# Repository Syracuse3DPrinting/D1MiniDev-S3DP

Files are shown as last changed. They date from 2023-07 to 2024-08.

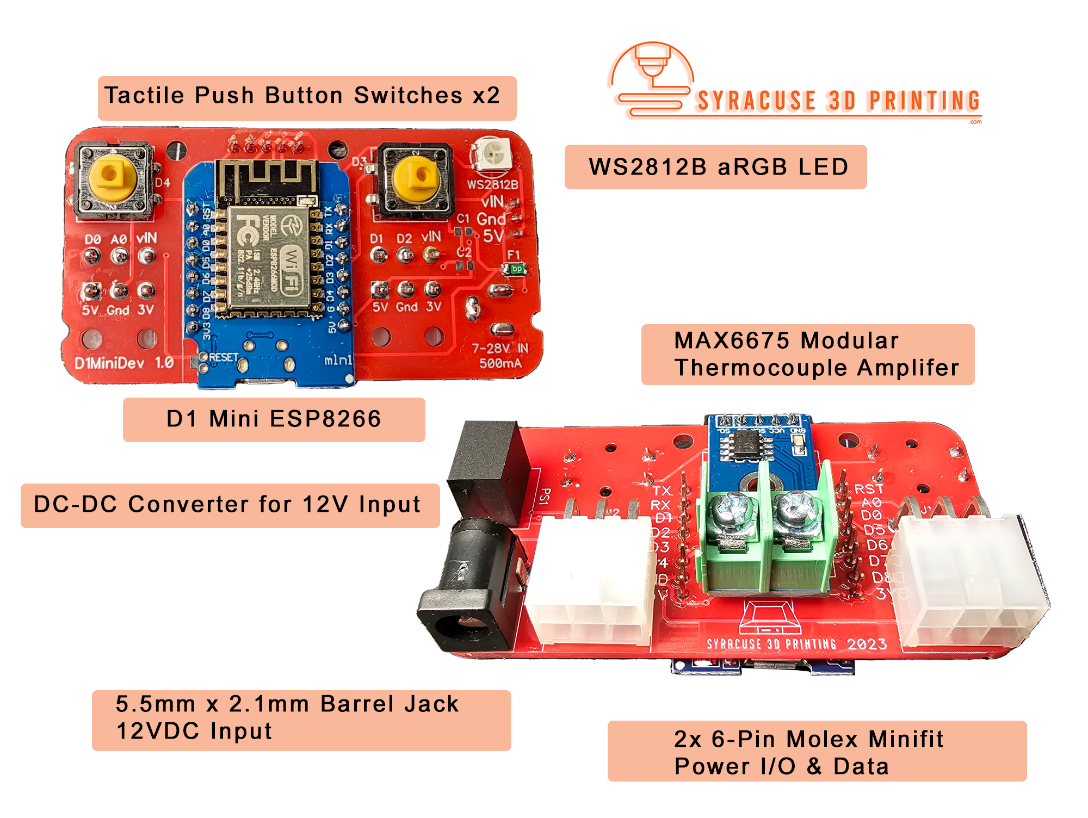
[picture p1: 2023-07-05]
Features.png

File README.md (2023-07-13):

# D1MiniDev-S3DP
## Syracuse 3D Printing D1 Mini Dev Board Resources

### In this repository:
- Technical Specifications & Instructions
- STL Models of Enclosure
- STEP Model of PCB w/Electronics to make your own enclosure
- Sample ESPHome Configuration
- Sample Home Assistant Automation for LED

### Available for purchase here as a bare PCB or fully assembled:
[https://syracuse3dprinting.com/product-category/smart-home/](https://syracuse3dprinting.com/product-category/smart-home/)

The D1MiniDev, designed by Syracuse3DPrinting, is a compact and versatile device ideal for DIY enthusiasts. Utilizing the well-regarded D1Mini ESP8266 microcontroller, this device provides a range of inputs and outputs suitable for a myriad of applications.

### Key Features:

**MAX6675 + K Type Thermocouple**: The device integrates a MAX6675 thermocouple amplifier and a K type thermocouple, which offer precise temperature measurements. This functionality is crucial for projects requiring temperature monitoring, including HVAC diagnostics.

**WS2812B RGB LED**: The D1MiniDev contains a programmable WS2812B RGB LED, which can be customized to change colors based on varying conditions, including temperature fluctuations.

**2x Momentary Push Buttons**: These buttons serve as binary inputs for Home Assistant, enabling users to control various aspects of their smart home system, such as adjusting lighting or activating scenes, directly from the device.

**Power Regulator with 7-28VDC and USB Input**: The D1MiniDev is designed with flexibility in mind, with a power regulator compatible with a wide array of power sources, ranging from 7 to 28VDC and including USB power.

**Dual 6 Pin Molex Minifit Connectors**: The D1MiniDev is equipped with dual 6 pin Molex minifit connectors, facilitating connectivity with other devices or modules and allowing for potential expansion of its functionality.

**ESPHome Configuration**: A sample ESPHome configuration for the D1MiniDev is available for download, ensuring a smooth integration process with the Home Assistant platform.

Users can choose between three different formats for the D1MiniDev: a bare PCB for those interested in a completely hands-on assembly experience; a DIY Kit that includes the PCB and components of your choice; or a fully assembled unit for immediate use. An optional 3D printed enclosure, purchasable or self-printable for those with a 3D printer, is available for added device protection.

### Technical Specifications: D1MiniDev by Syracuse3DPrinting

**Microcontroller**
- D1Mini ESP8266

**Temperature Measurement**
- MAX6675 Thermocouple Amplifier
- K Type Thermocouple

**Visual Indicator**
- WS2812B RGB LED (Programmable)

**User Inputs**
- 2x Momentary Push Buttons (Home Assistant Compatible)
- 3x Digital I/Os via 6-Pin Molex Headers
- 1x Analog I/O via 6-Pin Molex Headers

**Power Options**
- Power Regulator: 7-28VDC Input, 500mA
  - Optional onboard PTC Fuse is limited to 16VDC in
- USB Power Input - 5V via USB on D1 Mini
- Daisy Chain ability - When powered with 12V, Use 6-Pin headers to provide power from one board to another.
  - Recommended to bypass onboard fuse and use external fusing on the power supply for daisy chain applications

**Connectivity**
- Dual 6 Pin Molex Minifit Connectors (For Daisy Chaining and Expandability)
- Smart Home via Wifi (2.4ghz) - Designed for ESPHome via Home Assistant
  - Includes Sample ESPHome Configuration for Home Assistant Integration

**Form Factor Options**
- Bare PCB
- DIY Kit with PCB and Selected Components
- Fully Assembled Device

**Additional Accessories**
- Optional 3D Printed Enclosure (Purchasable or DIY Print)
- Please note that the final assembled size of the device will depend on the chosen components and the use of the optional enclosure.

## Bill of Materials

Most parts are optional based on configuration.

| Component | Specs | Part Number | Link |
| --- | --- | --- | --- |
| DC-DC Converter | 7-28VDCin 5VDC Out 500mA | R-78E5.0-0.5 | [DigiKey](https://www.digikey.com/en/products/detail/recom-power/R-78E5-0-0-5/2834904) |
| Power Supply Filtering Capacitors x2 | 10UF 10V X7R 0805 | CL21B106KPQNNNG | [DigiKey](https://www.digikey.com/en/products/detail/samsung-electro-mechanics/CL21B106KPQNNNG/3894474) |
| Push Button Tactile Switch x2 | - | B3F-4055 | [DigiKey](https://www.digikey.com/en/products/detail/omron-electronics-inc-emc-div/B3F-4055/31799) |
| PTC Resettable Fuse | 750 mA 16V | 0ZCJ0075AF2E | [DigiKey](https://www.digikey.com/en/products/detail/bel-fuse-inc/0ZCJ0075AF2E/4156135) |
| RGB Addressable LED | WS2812B | COM-16347 | [DigiKey](https://www.digikey.com/en/products/detail/sparkfun-electronics/COM-16347/11630204) |
| 6-Pin Molex MiniFit Header | - | 0353180620 | [DigiKey](https://www.digikey.com/en/products/detail/molex/0353180620/3185064) |
| 12V Power Input (5.5x2.1MM Barrel Jack) | - | CON-SOCJ-2155 | [Mouser](https://www.mouser.com/ProductDetail/Gravitech/CON-SOCJ-2155?qs=fkzBJ5HM%252BdCcpvFQyQZHtA%3D%3D) |
| D1 Mini ESP8266 | - | - | [Amazon](https://amzn.to/3rinfvB) |
| MAX6675 Module + K Type Thermocouple | 3-5V M6 | - | [Amazon](https://amzn.to/3rlv4Av) |

## Issues/Limitations

- The silkscreen outline of the ESP8266 is mirrored on v1.0 of the PCB. When assembling follow the assembly pictures instead of using the silkscreen outline for this component.
- The onboard PTC Fuse is limited to 16V. If using a 24VDC power supply it's recommended to bypass this fuse and use an external fuse.
- Some D1Mini clones may have issues with the Windows CH340 Driver. If you are unable to connect to the serial device via USB to PC you may need to roll back your drivers.
  - Here is a known working driver: https://web.archive.org/web/20211129002033/http://www.wch-ic.com/downloads/CH341SER_EXE.html

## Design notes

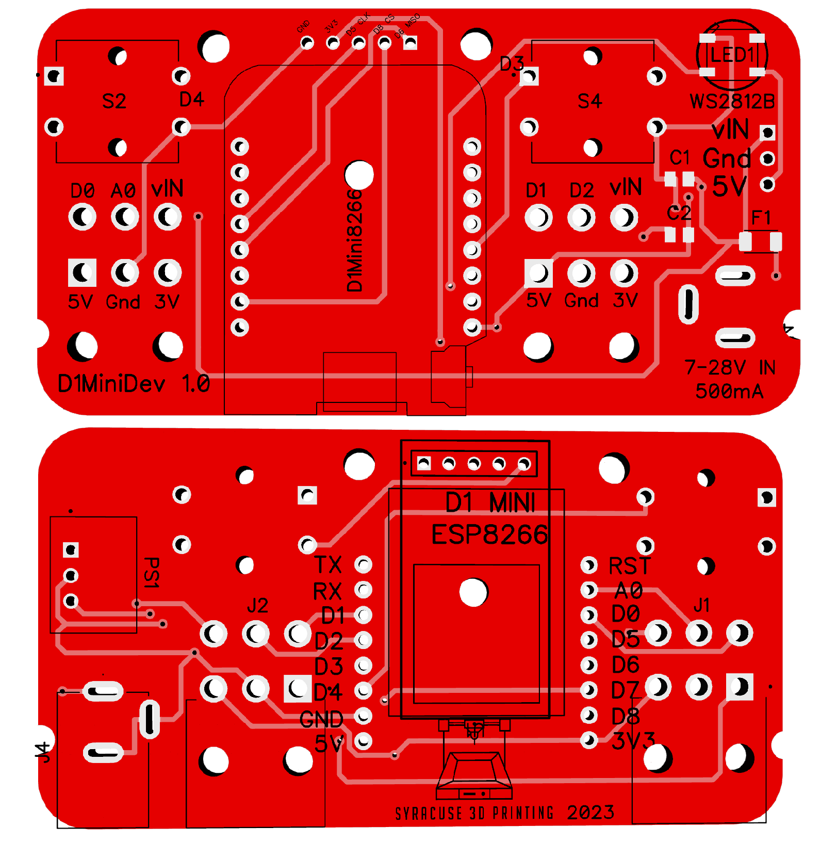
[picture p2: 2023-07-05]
PCB Overview.png

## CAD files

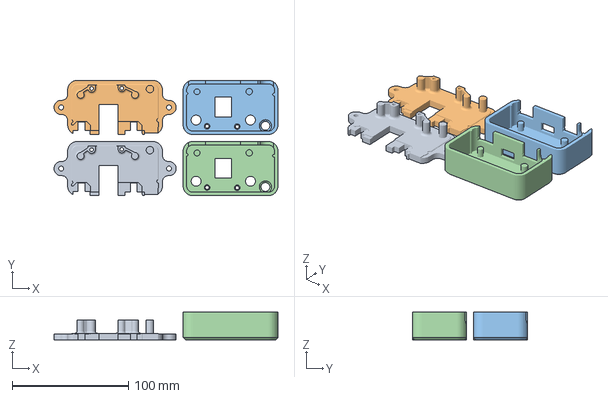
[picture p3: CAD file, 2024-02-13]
Enclosure/Ender3 - D1MiniDevBoardEnclosure1.2.3mf
192.7 x 99.2 x 24.0 mm
D1MiniDevBoardEnclosure1.2.STL_1
D1MiniDevBoardEnclosure1.2.STL_2

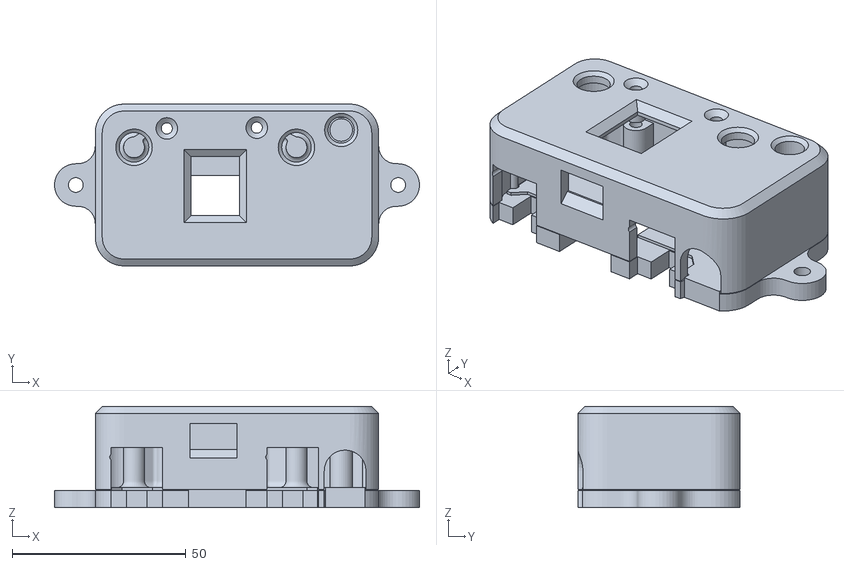
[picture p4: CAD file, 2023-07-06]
Enclosure/D1MiniDevBoardEnclosure1.2.STL
105.1 x 46.6 x 29.2

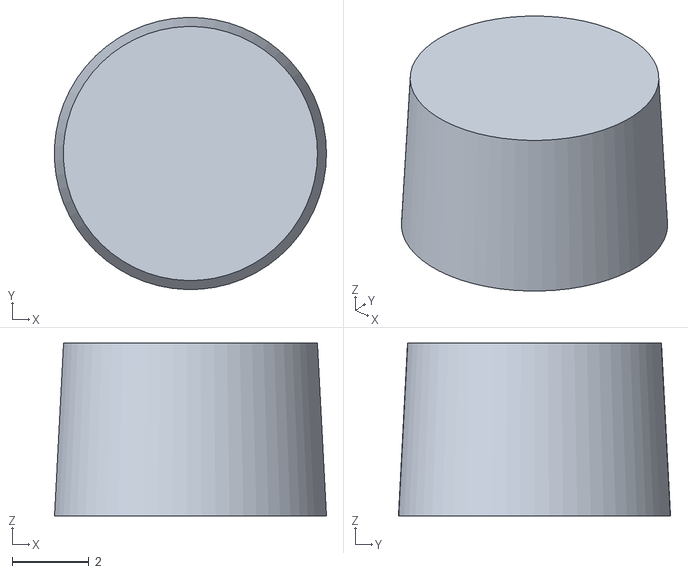
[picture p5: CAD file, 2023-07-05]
Enclosure/Switch Cap.STL
7.09 x 7.10 x 4.50

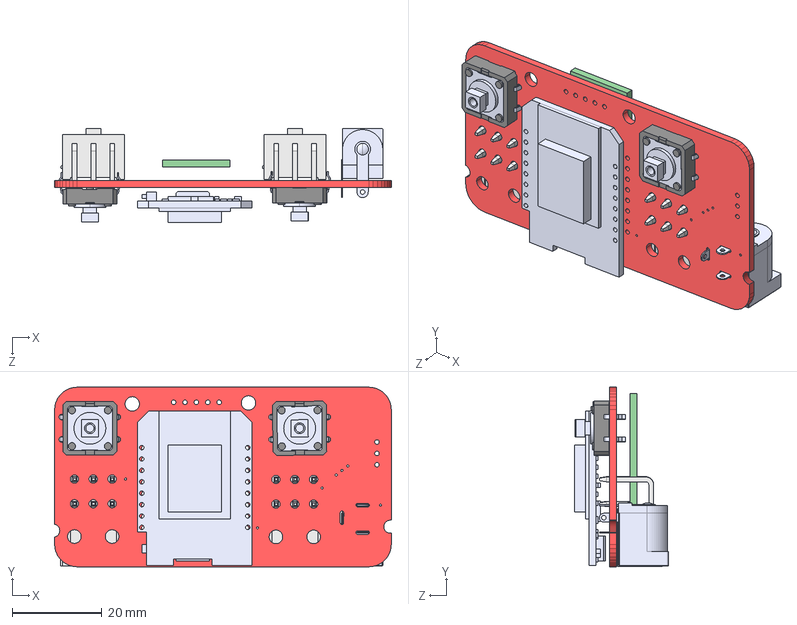
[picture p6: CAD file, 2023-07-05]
Enclosure/D1MiniDevBoardExport.step
75.1 x 40.0 x 21.0 mm
Board_D1MiniDevBoard.step
WEMOS_D1_miniLite.step
353180620.step x 2
CON-SOCJ-2155--3DModel-STEP-56544.step
MAX6675D.step
B3F-40551^B3F-4055.step x 2
B3F-40552^B3F-4055.step x 2
B3F-40553^B3F-4055.step x 2
B3F-40554^B3F-4055.step x 2
B3F-40555^B3F-4055.step x 2
B3F-40556^B3F-4055.step x 2
B3F-40557^B3F-4055.step x 2

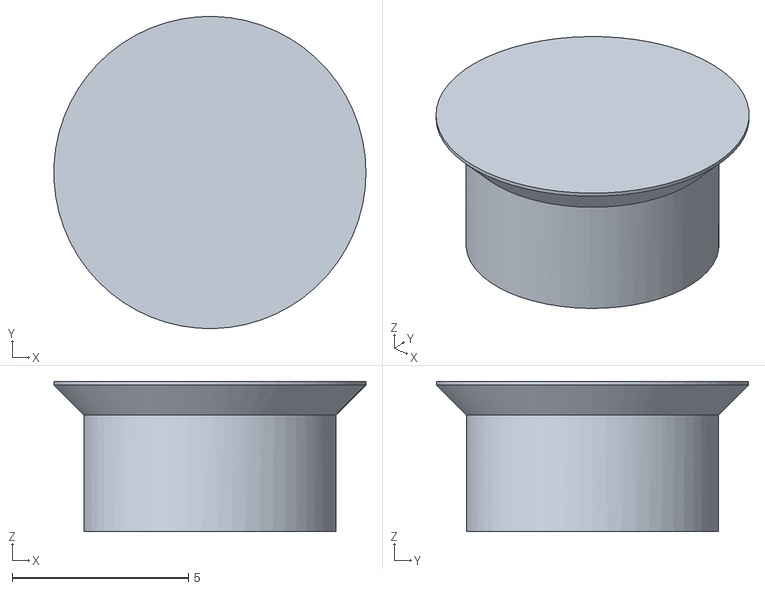
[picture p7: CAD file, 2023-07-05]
Enclosure/LED Lens.STL
8.84 x 8.84 x 4.25

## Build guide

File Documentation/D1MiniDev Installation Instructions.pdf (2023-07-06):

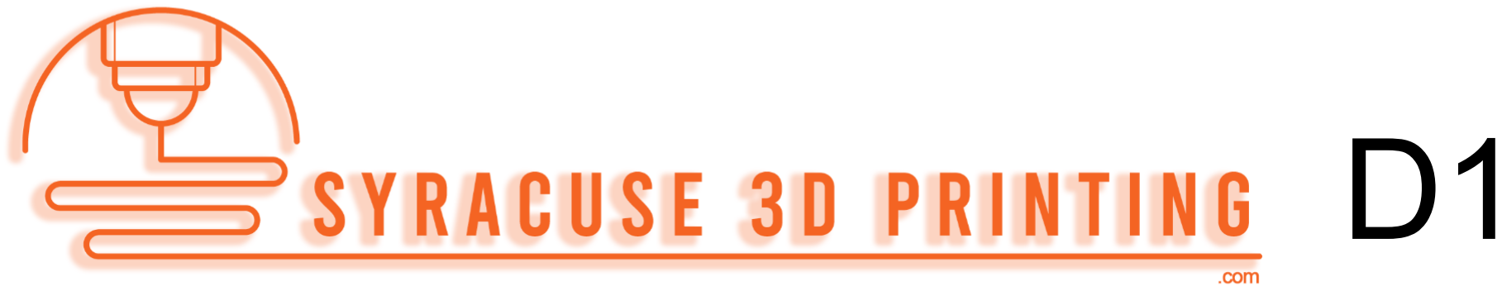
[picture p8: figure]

# D1 Mini Dev Installation Instructions

## Step 1: Physical Setup - Mounting the Thermocouple

1. For the temperature reading, you'll need to mount the K Type thermocouple in your desired location. This often involves drilling a hole and tapping it to match the M6 threading on the thermocouple.
2. Mark the location where you want to install the thermocouple. Make sure that the chosen location is safe for drilling, and will not interfere with other elements or components (like HVAC coils).
3. Drill a hole in the marked location using an appropriate drill bit.
4. Use an M6 tap to thread the hole. Carefully turn the tap to create clean threads.
5. Screw the thermocouple into the newly created hole, ensuring good contact for accurate temperature readings.
6. Connect the red lead to the + connection and the blue lead to the - termina

## Step 2: Wiring & Powering the Device

Depending on your application, the D1MiniDev can be powered via USB or by a 12V power supply.

### Powering via USB

Connect the D1MiniDev to your power source using a standard USB cable. Ensure the USB power source is capable of supplying at least 500mA.

### Powering via 12V - Models with DC-DC Converter installed only

1. Use a 12V DC Power supply with a 5MM barrel plug on it. The power supply should be rated for 750mA or greater. The center pin should be positive.
2. Connect the power supply to the D1MiniDev via the 5.5mm x 2.1mm barrel jack.

### Daisy Chain Power Configuration

For Daisy-Chain applications the 6-pin Molex Minifit connectors can be used to power 1 device from another device. Both devices must have a DC-DC Converter installed. It is recommended to use at least a 1A power. Use only the 12V and ground pins to supply power to a second device.

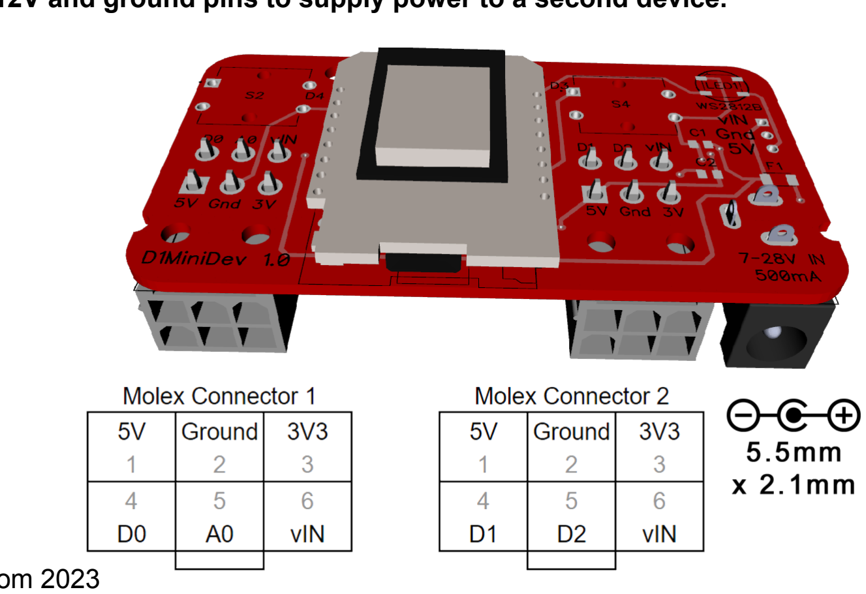
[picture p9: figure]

Syracuse3DPrinting.com 2023

## Step 3: ESPHome Setup

ESPHome is a system to control your ESP8266/ESP32 modules with simple yet powerful configuration files. It's fully integrated with Home Assistant.

1. Open the Home Assistant Dashboard, navigate to the "Supervisor" tab, and then "Add-on Store".
2. Install the ESPHome add-on.
3. In the ESPHome dashboard, click on the "+" button to add a new device.
4. Choose "Generic ESP8266" when asked for the device type.
5. Fill in the Wi-Fi SSID and password, and choose a suitable name for the device.
6. Once the device is online, open its configuration by clicking on "EDIT".
7. Replace the configuration with the provided D1MiniDev.yaml from the root directory of the GitHub repository. Don't forget to keep the Wi-Fi settings, OTA password, and API key generated by ESPHome for your particular installation.
8. Delete any sections that are not relevant to sensors you’re using. For instance if you do not have push buttons installed you can delete the binary sensor section.
9. You should now have a notification that a new device has been found. Follow the steps to set up this new device.
10. After completing these steps, your device should be ready for use, with the ability to monitor temperatures using the thermocouple and control the WS2812B RGB LED via Home Assistant.

## Step 4: 3D Printed Enclosure

The 3D Printed enclosure can be found on the main github repository. For assembly you’ll need the following:
- M3 x 30mm Flat Head Socket Bolts x2
- M3 Hex Nuts x2

Feel free to explore further possibilities of the device, such as setting up automations, customizing the LED behavior, or adding more devices to your smart home system.

## Disclaimer

Please note, this guide is provided for informational purposes only. All users are encouraged to independently validate their configurations according to their specific use cases and system requirements. While I strive to provide helpful and accurate information, I make no warranties or representations of any kind about the completeness, accuracy, or reliability of the information contained in this guide.

The suggested setups and configurations in this guide are based on my experience and testing, but I cannot guarantee that these will work in every environment or with every possible combination of hardware and software.

I strongly recommend referring to the official ESPHome documentation for a thorough understanding of how to use and configure ESPHome. This will give you the most accurate and up-to-date information regarding the installation, setup, and customization of your ESPHome devices. Visit ESPHome's official website for comprehensive and reliable guidance.

By using this guide, you agree that I am not responsible for any damage or loss caused by the use of the information contained in this guide. Always exercise safety precautions when working with electronics and follow all local, state, and national electrical codes.

Remember, the strength of the DIY community lies in sharing experiences, troubleshooting, and learning together. Enjoy your D1MiniDev journey!

Syracuse3DPrinting.com 2023

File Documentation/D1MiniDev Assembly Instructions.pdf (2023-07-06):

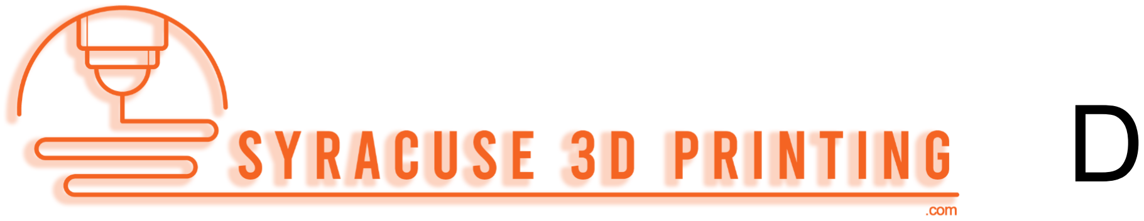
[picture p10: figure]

# D1 Mini Dev Assembly Instructions

Before starting, ensure you have all the components and tools required for assembly. A soldering iron, solder, a set of fine needle-nose pliers, and a PCB holder or vise will be needed.

Note: This assembly process involves advanced techniques including surface mount soldering. It is not recommended for beginners. If you're new to soldering or electronics assembly, consider seeking assistance from a more experienced individual or exploring some simpler projects to build your skills.

Remember: Your D1MiniDev DIY kit may not require all components listed in the Bill of Materials, as your configuration will vary based on your specific needs and preferences. Always review your setup and verify the components you need before beginning assembly.

### Step 1: Gather Your Materials

Ensure you have all components specified in the Bill of Materials. Lay them out on a clean, well-lit workspace. Familiarize yourself with the components and their corresponding locations on the PCB (Printed Circuit Board).

### Step 2: Power Supply Capacitors & Fuse - For 12V Power Supply Only

It's generally easiest to start soldering the smallest components first and work up to the larger ones. Start with the power supply filtering capacitors and PTC Resettable Fuse if they are included in your configuration.
- C1 & C2: Power Supply Filtering Capacitors (x2): Locate the appropriate pads on the PCB for the capacitors and solder them in place. These components are not polarized.
a. Note these components are strictly optional and are not needed with most power supplies. If you wish to omit them from your build simple do nothing with these pads.
- F1: PTC Resettable Fuse: Identify the correct location for the fuse on the PCB. The fuse is non-polar, so it can be placed in either orientation.
a. Note the fuse is optional if using a 12V power supply with short circuit protection. In the event you wish not to use the fuse simply use a small piece of wire to cross the contacts of F1.

### Step 3: Solder the DC-DC Converter

- PS1: If your configuration includes the DC-DC converter, find its corresponding pads on the PCB. The converter should be inserted from the bottom of the board and match up with the footprint. Solder into place and trim any excess leads if necessary.

### Step 4: Install the Momentary Push Buttons

- S2 & S4: Locate the correct locations for the momentary push buttons on the PCB, if they are part of your configuration. Ensure they are oriented correctly and securely fastened before soldering. After insertion, flip the PCB over and solder them into place.

### Step 5: Install the Molex Connectors and Power Input

- J1, J2 & J4: Next, install the Molex Minifit connectors and the power input, if they are included in your setup. Ensure the orientation of these components is correct before soldering them in place.

Syracuse3DPrinting.com 2023

### Step 6: Solder the RGB LED

- LED1: Identify the correct location for the RGB LED on the PCB if it's part of your setup. Note the orientation before placement, aligning the notch or dot on the LED with the symbol on the PCB.

### Step 7: Install the D1 Mini and MAX6675 Module

- MAX6675: If using the K-Type thermocouple you can install the MAX6675 module. If the module came equipped with a right-angle header you will need to desolder this header and replace it with a vertical pin header.
- D1MINI: For the D1 Mini, ensure that the USB port is facing the edge of the board. Make sure the D1 Mini is oriented per the documentation.
- Please note the silkscreen on version 1.0 of the board is not accurate.

Remember to take your time while soldering to avoid overheating any components. Apply the soldering iron to the junction of the component lead and the pad, then apply solder to the junction, not directly to the iron.

After you've completed soldering all components, give your board a visual inspection. Look for any loose components, excess solder, or bridges between pads.

Congratulations, your D1MiniDev is now assembled and ready for use! Refer back to the installation instructions and Home Assistant setup to get your D1MiniDev up and running.

Important: This guide assumes knowledge of surface mount device (SMD) soldering techniques. SMD components can be very small and may require a precision soldering iron and fine solder. Experience with soldering is strongly recommended before attempting to assemble this DIY kit. If you're not confident in your soldering skills, consider seeking help from someone with experience.

Remember: practice safety when working with electronic devices and always follow local and national electrical codes. Enjoy your new DIY D1MiniDev!

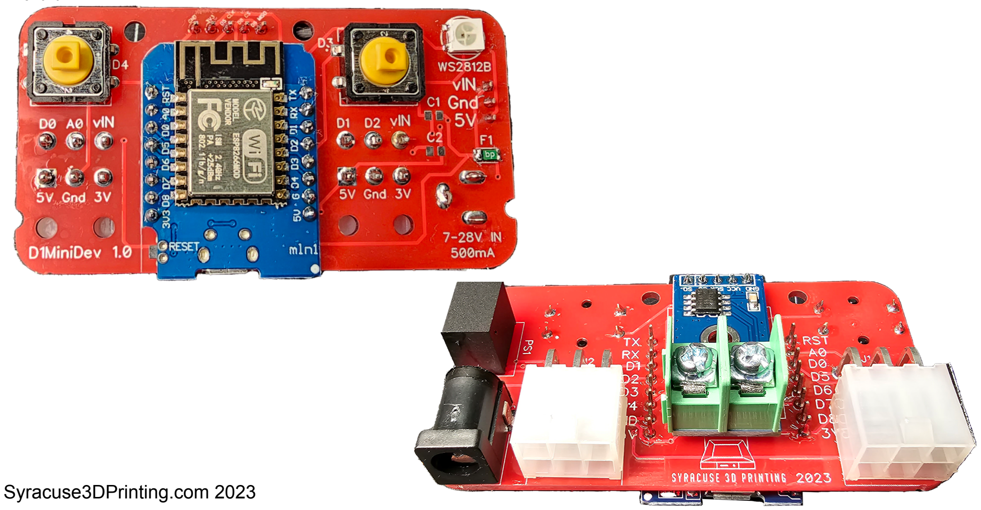
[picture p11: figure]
Syracuse3DPrinting.com 2023

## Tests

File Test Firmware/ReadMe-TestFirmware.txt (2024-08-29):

Test Firmware is ESPHome with no internet connectivity. 

This tests full functionality of the module without needing to be connected to your Home Assistant instance. 

To use this firmware:

Download ESPHome Flasher https://github.com/esphome/esphome-flasher/releases

-or-

Use ESPHome Web Flasher https://web.esphome.io/

Plug in ESP8266 via USB. Select COM port. Select firmware QC file. 

Once install is complete log window should display button press changes and temperature readings. 

LED should cycle colors in a test pattern.

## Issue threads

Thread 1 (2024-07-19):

Any chance you could share the Gerber's for the PCB? I see the store is no longer up.

Sperryfreak01, 2024-07-19:

Syracuse3DPrinting, 2024-07-23:
@Sperryfreak01 the store is down temporarily while I sort through some issues with the registrar.

You can email me directly for orders or tech specs not available here.

Thanks
-Dan
info@iptindustries.com

Sperryfreak01, 2024-07-23:
Oh cool.  I'm not in a big rush, I've got a few projects on the list currently.  If I clear those and it's still down I'll shoot you a message.

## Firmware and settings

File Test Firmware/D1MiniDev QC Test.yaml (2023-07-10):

# Define the ESPHome device and settings
esphome:
  # Name of the device
  name: d1minidev1_qc_test
  # Actions to perform on device boot
  on_boot:
    # Priority of the boot actions, lower values execute earlier
    - priority: -10
      then:
        # Turn on the light with the specified id and effect on boot
        - light.turn_on:
            id: test_light
            effect: "Color Wipe"

# Define the ESP8266 board and framework version
esp8266:
  framework:
    version: 2.7.4
  board: d1_mini

# Configure logger for debug information
logger:

# SPI interface configuration
spi:
  # ID of the SPI interface
  id: probe1
  # Clock pin for the SPI interface
  clk_pin: D5
  # MISO pin for the SPI interface
  miso_pin: D6

# Sensor configuration
sensor:
  - platform: max6675
    # ID of the SPI interface to use for the sensor
    spi_id: probe1
    # Name of the sensor
    name: "D1Mini1 Thermocouple Temperature"
    # Chip Select pin for the sensor
    cs_pin: D8
    # Interval to update the sensor reading
    update_interval: 5s

# Binary sensor configuration
binary_sensor:
  # First switch configuration
  - platform: gpio
    pin:
      # GPIO pin number for the switch
      number: D4
      # GPIO pin mode
      mode: INPUT_PULLUP
      # Invert the switch reading
      inverted: true
    name: "D1 Mini Switch 1"
    on_press:
      then:
        # Log a message when the switch is pressed
        - logger.log: "Switch 1 pressed"

  # Second switch configuration
  - platform: gpio
    pin:
      number: D3
      mode: INPUT_PULLUP
      inverted: true
    name: "D1 Mini Switch 2"
    on_press:
      then:
        - logger.log: "Switch 2 pressed"

# Light configuration
light:
  - platform: fastled_clockless
    # ID of the light
    id: test_light
    # Chipset of the LED strip
    chipset: WS2812B
    # GPIO pin connected to the LED strip
    pin: D7
    # Number of LEDs in the strip
    num_leds: 1
    # Order of the RGB channels in the LED strip
    rgb_order: GRB
    # Name of the light
    name: "FastLED WS2811 Light"
    # Define the light effects
    effects:
      # Color wipe effect configuration
      - addressable_color_wipe:
          # Name of the effect
          name: "Color Wipe"
          # Colors to cycle in the color wipe effect
          colors:
            - red: 100%
              green: 0%
              blue: 0%
              num_leds: 1
            - red: 0%
              green: 100%
              blue: 0%
              num_leds: 1
            - red: 0%
              green: 0%
              blue: 100%
              num_leds: 1
          # Time interval to add an LED to the wipe
          add_led_interval: 100ms
          # Direction of the color wipe
          reverse: False

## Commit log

2023-07-05 Main commit
    [D1MiniDevBoardEnclosure.STL, D1MiniDevBoardExport.step, LED Lens.STL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]
2023-07-05 Added BoM to Readme
2023-07-06 Modified enclosure
    [D1MiniDevBoardEnclosure.STL, D1MiniDevBoardEnclosure1.2.STL]
2023-07-13 Added Calibration
    Added calibration option to sample configuration
2023-07-13 Update README.md
    Added known working driver for CH340 Serial to USB
2023-07-13 Create Example Template Sensor for HVAC Delta.yaml
2023-07-13 Update Example Template Sensor for HVAC Delta.yaml
2023-07-13 Update LED Color Change with HVAC Delta Temp.yaml
2024-02-13 Create Ender3 - D1MiniDevBoardEnclosure1.2.3mf
    [Ender3 - D1MiniDevBoardEnclosure1.2.3mf]
2024-02-20 Fixed issues with old framework compiler
    Moved framework to default.
    Changed fastled_clockless to standard fastled with external github files in ESPHome config.
    Updated QC YAML, QC bin, and commented ESPHome YAML.
    [D1MiniDev QC Test_old.yaml]
